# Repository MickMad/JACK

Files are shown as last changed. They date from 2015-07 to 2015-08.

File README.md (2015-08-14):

#JACK
##Just Another Cortex Kit

A Cortex-M0+ development kit with an Atmel SAM D21, a USB device port, a regulator, some passives, a programming header, and breakout headers.

Arduino Zero compatible.

Software is here:

https://github.com/MickMad/ArduinoCore-samd/

```
Copyright © Michele Perla 2015

This documentation describes Open Hardware and is licensed under the CERN OHL v. 1.2.
You may redistribute and modify this documentation under the terms of the CERN OHL v.1.2. 
(http://ohwr.org/cernohl). This documentation is distributed
WITHOUT ANY EXPRESS OR IMPLIED WARRANTY, INCLUDING OF
MERCHANTABILITY, SATISFACTORY QUALITY AND FITNESS FOR A
PARTICULAR PURPOSE. Please see the CERN OHL v.1.2 for applicable
conditions
```

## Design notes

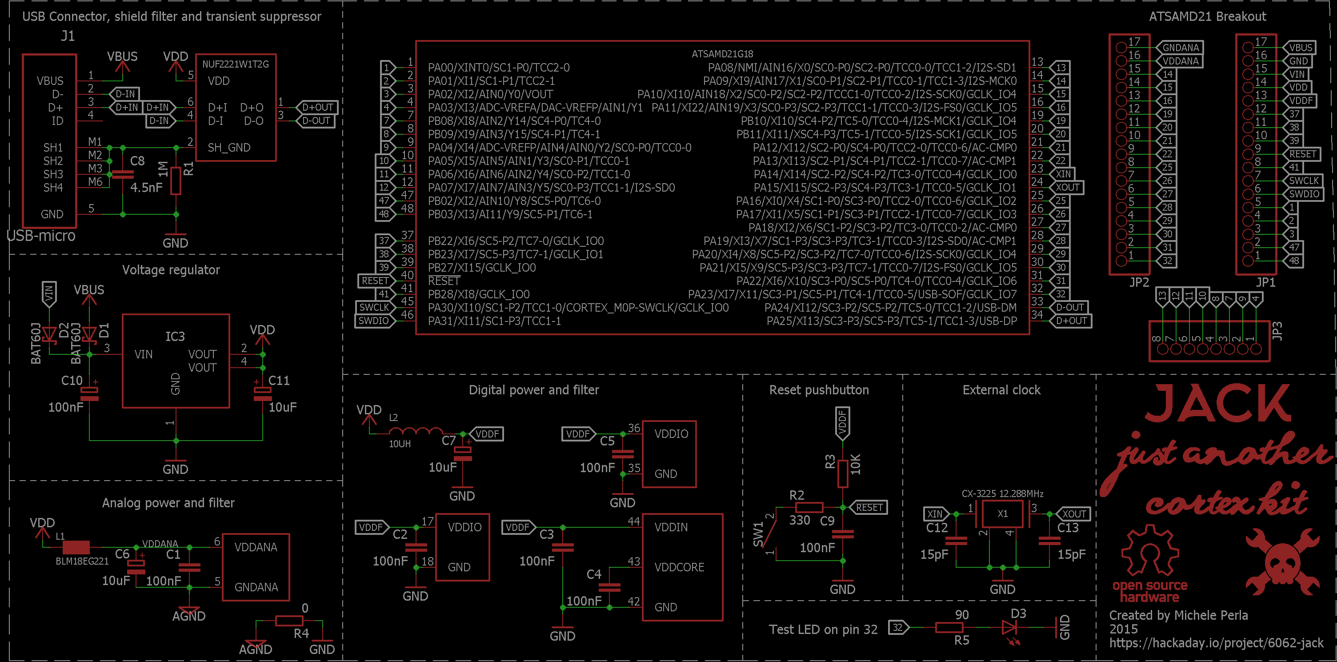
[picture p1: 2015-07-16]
graphics/jack - schematic.png

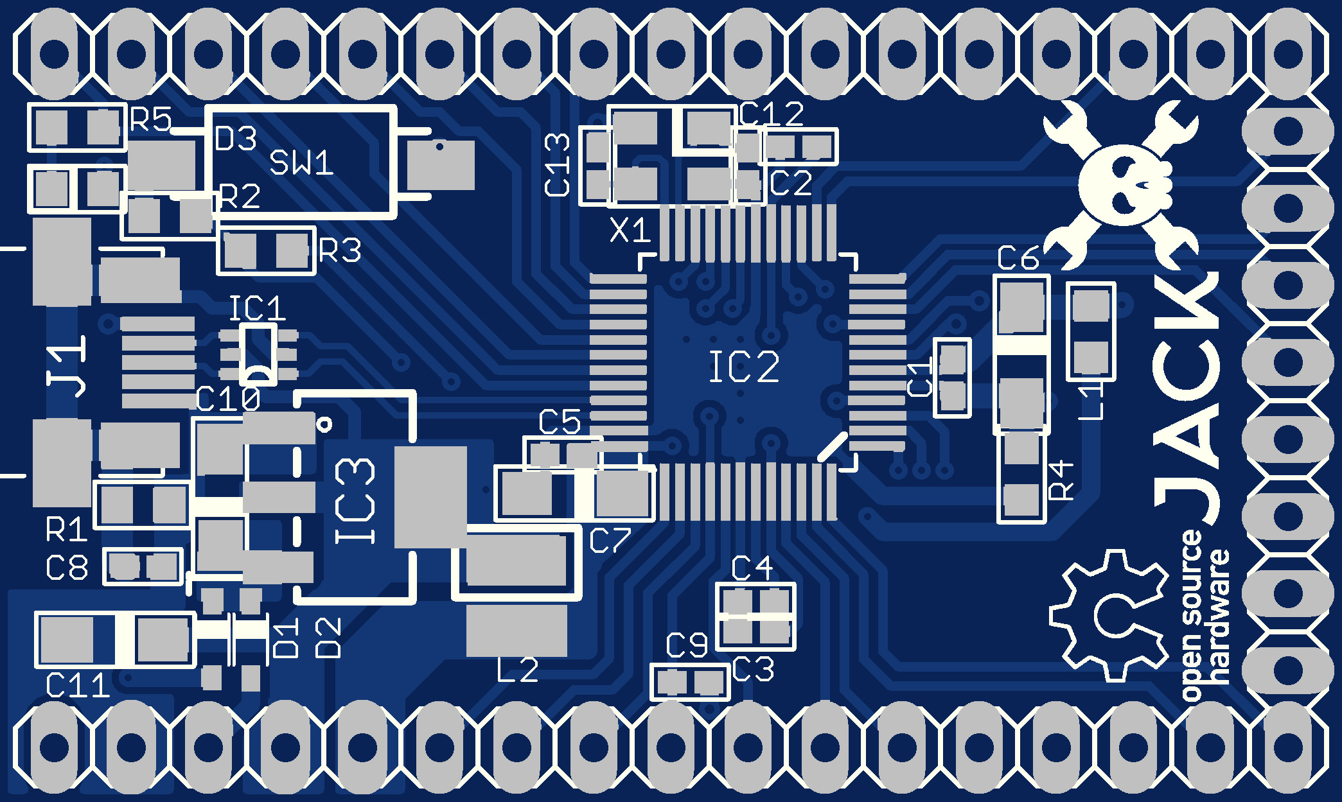
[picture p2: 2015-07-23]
eagleUp/eagleUp_jack_board_top.jpg

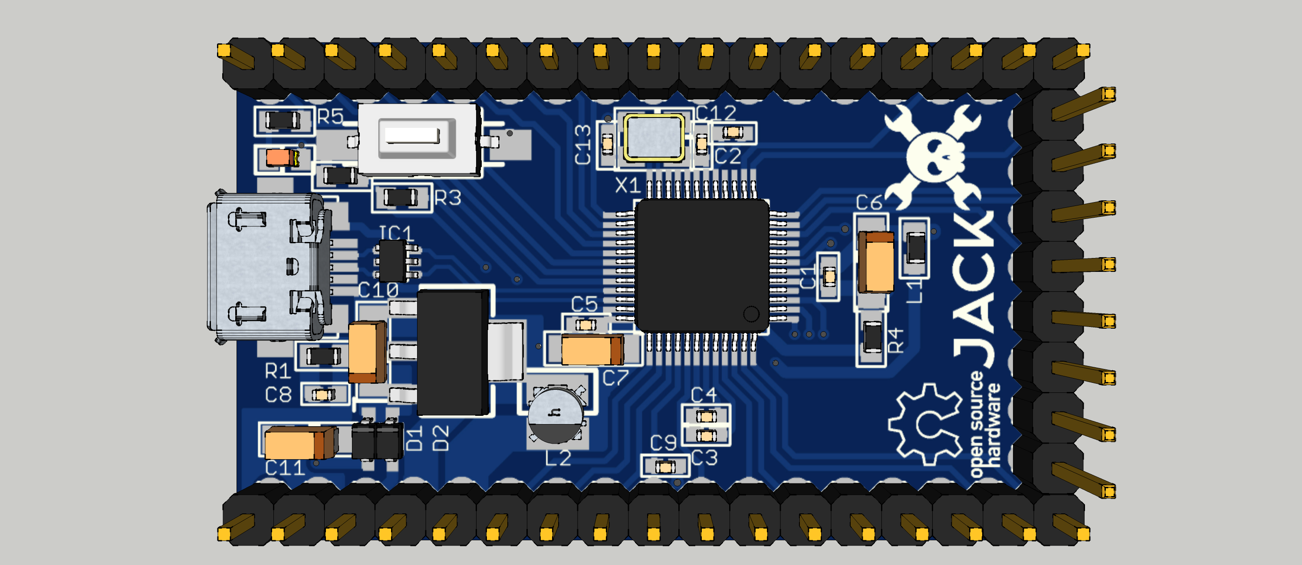
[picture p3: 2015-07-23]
graphics/jack - 3D preview - top.png

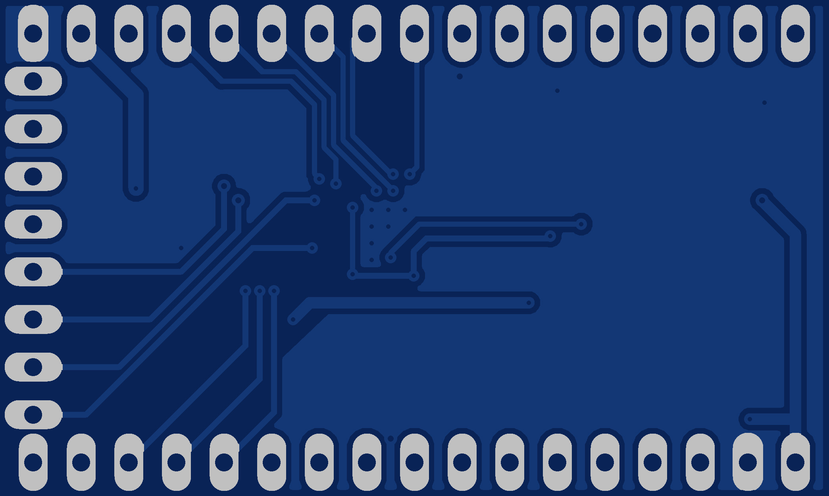
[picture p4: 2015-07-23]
eagleUp/eagleUp_jack_board_bottom.jpg

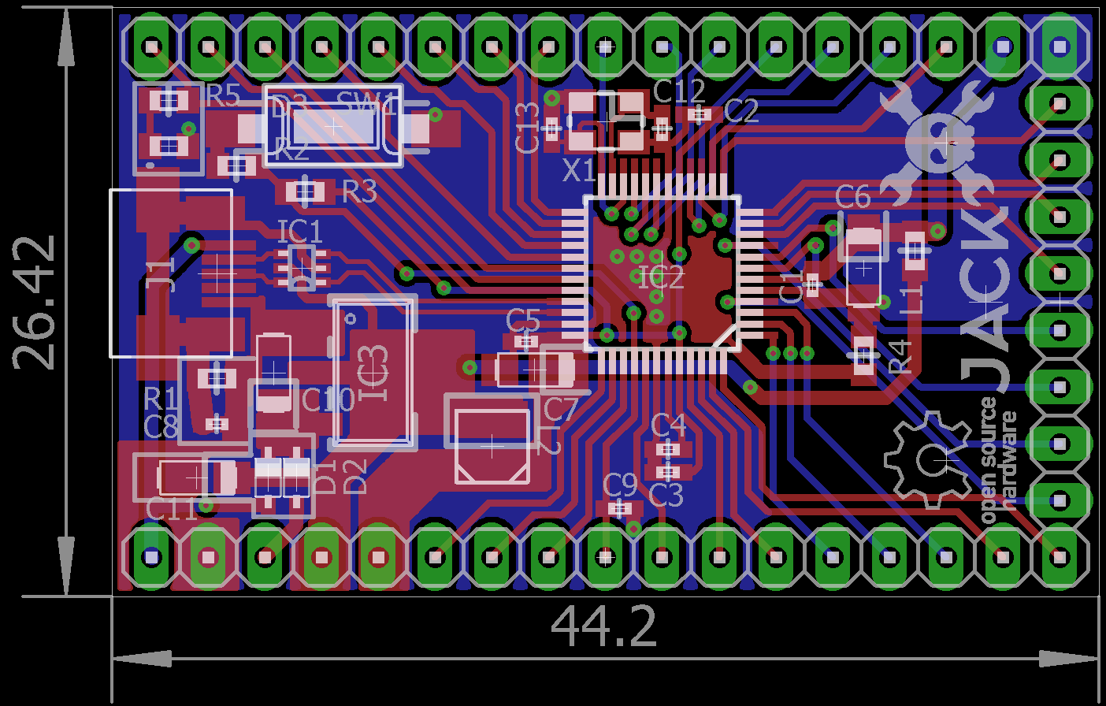
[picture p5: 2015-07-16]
graphics/jack - layout.png

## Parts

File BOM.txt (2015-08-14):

Partlist exported from C:/Users/mperla.CORP/Documents/GitHub/JACK/jack.sch at 16/07/2015 16:05

Part Value             Device          Package            Description                                                            
C1   100nF             C-EU            C0402K                                                                                    
C2   100nF             C-EU            C0402K                                                                                    
C3   100nF             C-EU            C0402K                                                                                    
C4   100nF             C-EU            C0402K                                                                                    
C5   100nF             C-EU            C0402K                                                                                  
C9   100nF             C-EU            C0402K

C8   4.5nF             C-EU            C0402K  
                                                                                    
C6   10uF              CPOL-EU         SMC_P                                                                                     
C7   10uF              CPOL-EU         SMC_P                                                                                                                                                                        
C10  10uF              CPOL-EU         SMC_P                                                                                     
C11  10uF              CPOL-EU         SMC_P   
                                                                                  
C12  15pF              C-EU            C0402K                                                                                    
C13  15pF              C-EU            C0402K 
                                                                                   
D1   BAT60J            BAT60J          SOD323_ST          Schottky barrier diode                                                 
D2   BAT60J            BAT60J          SOD323_ST          Schottky barrier diode  
                                               
D3   LED               LED             LED-0603           Blue LED                                                               
IC1  NUF2221W1T2G      NUF2221W1T2G    SOT-363            ON SEMICONDUCTOR NUF2221W1T2G  IC, FILTER, USB, ESD PROTECTION, SOT363 
IC2  ATSAMD21G18       ATSAMD21G18     TQFP48                                                                                    
IC3  NCV1117ST33T3G    NCV1117ST33T3G  SOT-223-3          ON Semiconductor LDO 3.3V 1.0A Automotive                                                                       
J1   USB-micro         47346-0001      MOLEX_47346-0001   CONN RCPT 5POS MICRO USB R/A  SMD                                      

JP1                    PINHD-1X17      1X17               PIN HEADER                                                             
JP2                    PINHD-1X17      1X17               PIN HEADER                                                             
JP3                    PINHD-1X8       1X08               PIN HEADER  
                                                           
L1   BLM18EG221        L               0603               Ferrite bead                                                           
L2   10UH              ELLVFG100MC-VXG IND_ELLVXG         Choke Coils   
                                                         
R1   1M                R-EU            R0603                                                                                     
R2   330               R-EU            R0603                                                                                     
R3   10K               R-EU            R0603                                                                                     
R4   0                 R-EU            R0603                                                                                     
R5   68                R-EU            R0603     
                                                                                
SW1  SPST3.5X6MM       SPST3.5X6MM     SWITCH-SMD-3.5X6MM Tactile Switches 3.5X6 SMT TACT TACT SWITCH - Mouser part # 506-FSMSM                                                                                 
X1   CX-3225 12.288MHz XTALCX-3225     CX-3225

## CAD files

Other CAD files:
graphics/jack.skp

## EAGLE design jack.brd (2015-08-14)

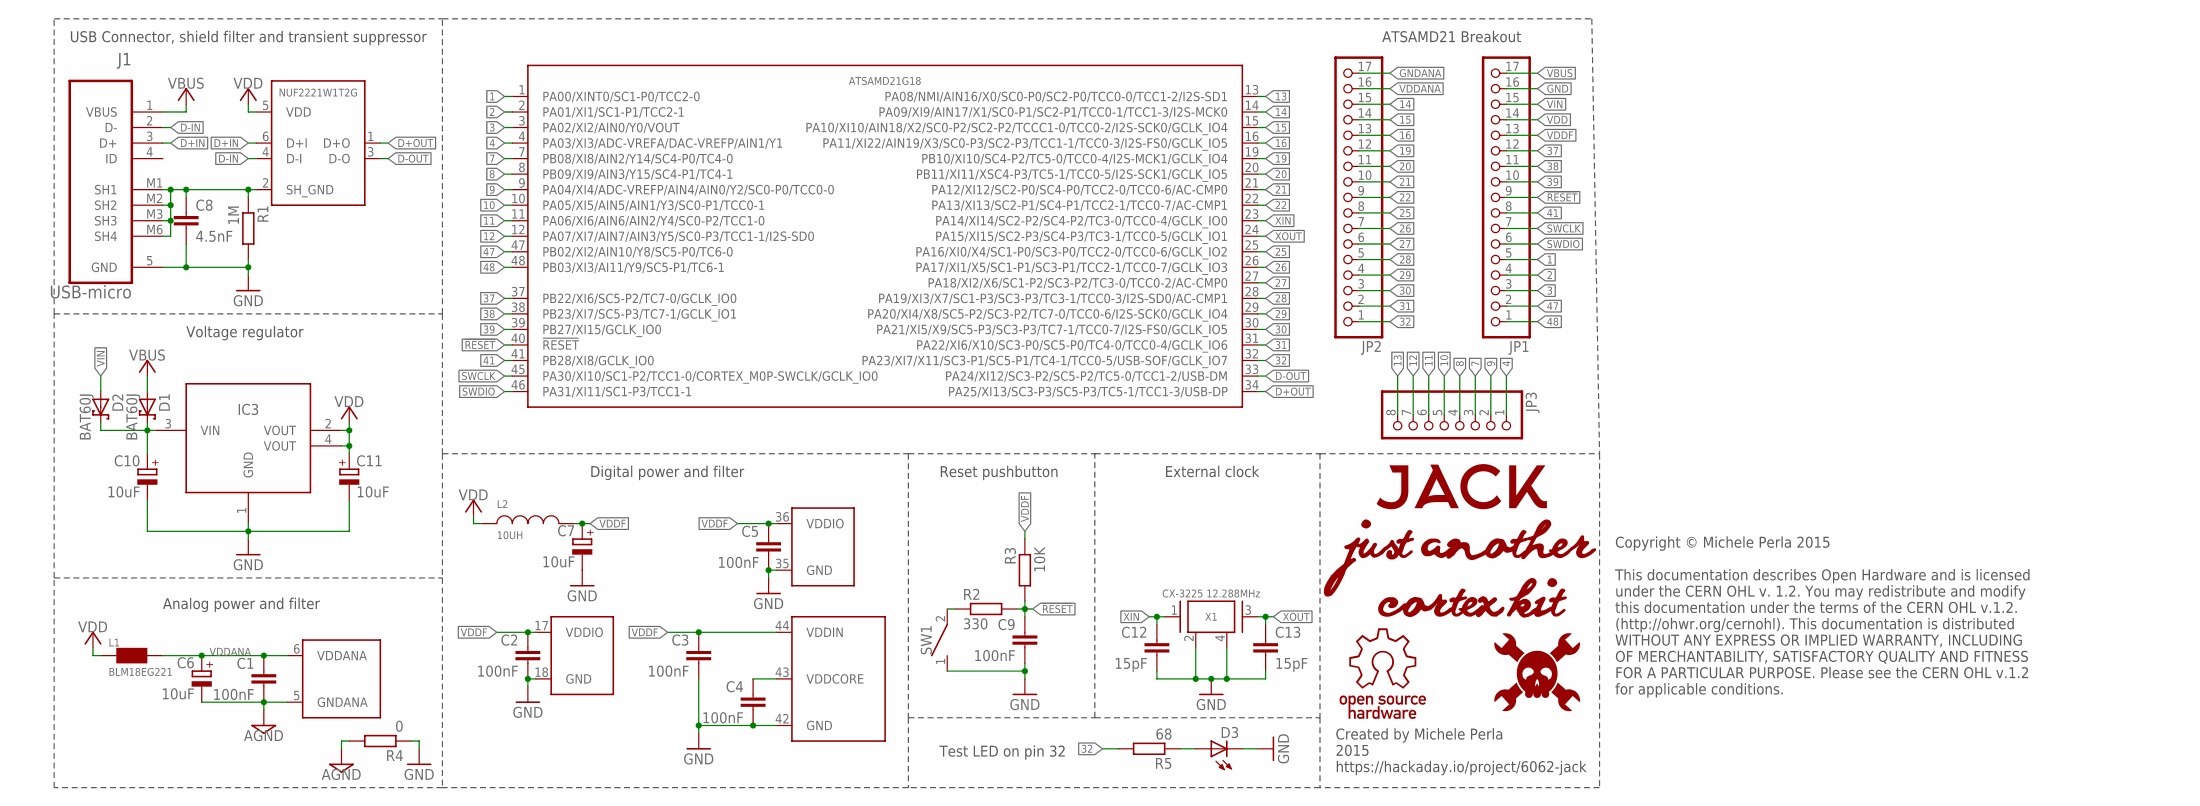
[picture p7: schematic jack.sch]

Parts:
C1, C2, C3, C4, C5, C9: 100nF; C0402
C6, C7, C10, C11: 10uF; CT3216
C8: 4.5nF; C0402
C12, C13: 15pF; C0402
D1, D2: BAT60J; SOD323_ST
D3: LED; LED-0603
IC1: NUF2221W1T2G; SOT-363
IC2: ATSAMD21G18; TQFP48
IC3: LDO; SOT-223-3
J1: USB-micro; MOLEX_47346-0001
JP1, JP2: PINHD-1X17; 1X17
JP3: PINHD-1X8; 1X08
L1: BLM18EG221; 0603
L2: 10UH; IND_ELLVXG
R1: 1M; R0603
R2: 330; R0603
R3: 10K; R0603
R4: 0; R0603
R5: 68; R0603
SW1: SPST3.5X6MM; SWITCH-SMD-3.5X6MM
U$3: JACK-LOGO
U$5: HAD-LOGO
U$6: OSHW-LOGO
X1: CX-3225 12.288MHz; CX-3225

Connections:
1: IC2.1 (PA00/XINT0/SC1-P0/TCC2-0), JP1.5
2: IC2.2 (PA01/XI1/SC1-P1/TCC2-1), JP1.4
3: IC2.3 (PA02/XI2/AIN0/Y0/VOUT), JP1.3
4: IC2.4 (PA03/XI3/ADC-VREFA/DAC-VREFP/AIN1/Y1), JP3.1
7: IC2.7 (PB08/XI8/AIN2/Y14/SC4-P0/TC4-0), JP3.3
8: IC2.8 (PB09/XI9/AIN3/Y15/SC4-P1/TC4-1), JP3.4
9: IC2.9 (PA04/XI4/ADC-VREFP/AIN4/AIN0/Y2/SC0-P0/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), JP3.2
10: IC2.10 (PA05/XI5/AIN5/AIN1/Y3/SC0-P1/TCC0-1), JP3.5
11: IC2.11 (PA06/XI6/AIN6/AIN2/Y4/SC0-P2/TCC1-0), JP3.6
12: IC2.12 (PA07/XI7/AIN7/AIN3/Y5/SC0-P3/TCC1-1/I2S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), JP3.7
13: IC2.13 (PA08/NMI/AIN16/X0/SC0-P0/SC2-P0/TCC0-0/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), JP3.8
14: IC2.14 (PA09/XI9/AIN17/X1/SC0-P1/SC2-P1/TCC0-1/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), JP2.15
15: IC2.15 (PA10/XI10/AIN18/X2/SC0-P2/SC2-P2/TCCC1-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), JP2.14
16: IC2.16 (PA11/XI22/AIN19/X3/SC0-P3/SC2-P3/TCC1-1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), JP2.13
19: IC2.19 (PB10/XI10/SC4-P2/TC5-0/TCC0-4/I2S-MCK1/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), JP2.12
20: IC2.20 (PB11/XI11/XSC4-P3/TC5-1/TCC0-5/I2S-SCK1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), JP2.11
21: IC2.21 (PA12/XI12/SC2-P0/SC4-P0/TCC2-0/TCC0-6/A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), JP2.10
22: IC2.22 (PA13/XI13/SC2-P1/SC4-P1/TCC2-1/TCC0-7/A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), JP2.9
25: IC2.25 (PA16/XI0/X4/SC1-P0/SC3-P0/TCC2-0/TCC0-6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), JP2.8
26: IC2.26 (PA17/XI1/X5/SC1-P1/SC3-P1/TCC2-1/TCC0-7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), JP2.7
27: IC2.27 (PA18/XI2/X6/SC1-P2/SC3-P2/TC3-0/TCC0-2/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), JP2.6
28: IC2.28 (PA19/XI3/X7/SC1-P3/SC3-P3/TC3-1/TCC0-3/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), JP2.5
29: IC2.29 (PA20/XI4/X8/SC5-P2/SC3-P2/TC7-0/TCC0-6/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), JP2.4
30: IC2.30 (PA21/XI5/X9/SC5-P3/SC3-P3/TC7-1/TCC0-7/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), JP2.3
31: IC2.31 (PA22/XI6/X10/SC3-P0/SC5-P0/TC4-0/TCC0-4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), JP2.2
32: IC2.32 (PA23/XI7/X11/SC3-P1/SC5-P1/TC4-1/TCC0-5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), JP2.1, R5.2
37: IC2.37 (PB22/XI6/SC5-P2/TC7-0/GCLK_IO0), JP1.12
38: IC2.38 (PB23/XI7/SC5-P3/TC7-1/GCLK_IO1), JP1.11
39: IC2.39 (PB27/XI15/GCLK_IO0), JP1.10
41: IC2.41 (PB28/XI8/GCLK_IO0), JP1.8
47: IC2.47 (PB02/XI2/AIN10/Y8/SC5-P0/TC6-0), JP1.2
48: IC2.48 (PB03/XI3/AI11/Y9/SC5-P1/TC6-1), JP1.1
!RESET: C9.1, IC2.40 (!RESET), JP1.9, R2.2, R3.2
D+IN: IC1.6 (D+I), J1.3 (D+)
D+OUT: IC1.1 (D+O), IC2.34 (PA25/XI13/SC3-P3/SC5-P3/TC5-1/TCC1-3/US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)
D-IN: IC1.4 (D-I), J1.2 (D-)
D-OUT: IC1.3 (D-O), IC2.33 (PA24/XI12/SC3-P2/SC5-P2/TC5-0/TCC1-2/US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)
GND: C2.2, C3.2, C4.2, C5.2, C7.-, C8.2, C9.2, C10.-, C11.-, C12.2, C13.2, D3.C, IC2.18 (GND), IC2.35 (GND), IC2.42 (GND), IC3.1 (GND), J1.5 (GND), JP1.16, R1.2, R4.1, SW1.1, X1.2 (GND), X1.4 (GND)
GNDANA: C1.2, C6.-, IC2.5 (GNDANA), JP2.17, R4.2
LDOIN: C10.+, D1.C, D2.C, IC3.3 (VIN)
unnamed: D3.A, R5.1
unnamed: R2.1, SW1.2
SH_GND: C8.1, IC1.2 (SH_GND), J1.M1 (SH1), J1.M2 (SH2), J1.M3 (SH3), J1.M6 (SH4), R1.1
SWCLK: IC2.45 (PA30/XI10/SC1-P2/TCC1-0/CORTEX_M0P-SWCL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), JP1.7
SWDIO: IC2.46 (PA31/XI11/SC1-P3/TCC1-1), JP1.6
VBUS: D1.A, J1.1 (VBUS), JP1.17
VDD: C11.+, IC1.5 (VDD), IC3.2 (VOUT), IC3.4 (VOUT), JP1.14, L1.1, L2.2
VDDANA: C1.1, C6.+, IC2.6 (VDDANA), JP2.16, L1.2
VDDCORE: C4.1, IC2.43 (VDDCORE)
VDDF: C2.1, C3.1, C5.1, C7.+, IC2.17 (VDDIO), IC2.36 (VDDIO), IC2.44 (VDDIN), JP1.13, L2.1, R3.1
VIN: D2.A, JP1.15
XIN: C12.1, IC2.23 (PA14/XI14/SC2-P2/SC4-P2/TC3-0/TCC0-4/GC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), X1.1
XOUT: C13.1, IC2.24 (PA15/XI15/SC2-P3/SC4-P3/TC3-1/TCC0-5/GC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), X1.3

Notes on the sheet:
USB Connector, shield filter and transient suppressor
Voltage regulator
Analog power and filter
Digital power and filter
Reset pushbutton
External clock
ATSAMD21 Breakout
Created by Michele Perla 2015 https://hackaday.io/project/6062-jack
Test LED on pin 32
Copyright © Michele Perla 2015 This documentation describes Open Hardware and is licensed under the CERN OHL v. 1.2. You may redistribute and modify this documentation under the terms of the CERN OHL v.1.2. (http://ohwr.org/cernohl). This documentation is distributed WITHOUT ANY EXPRESS OR IMPLIED 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

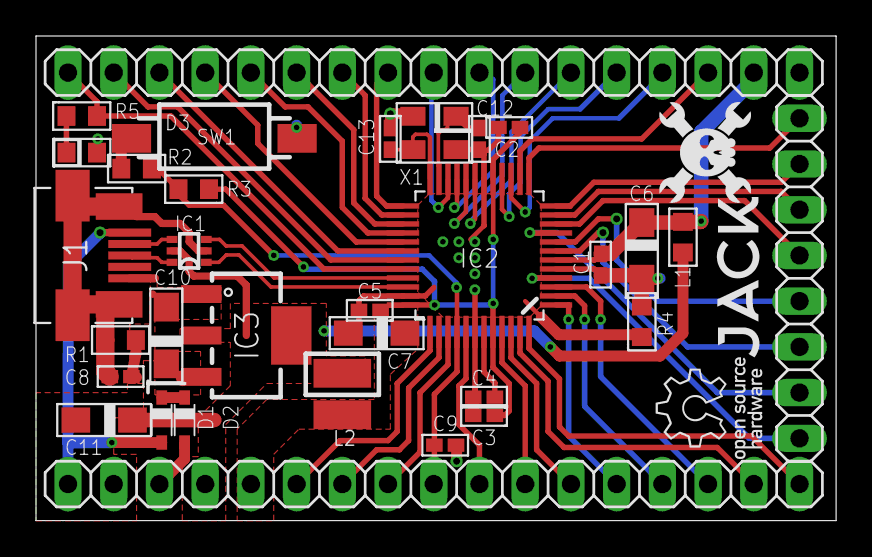
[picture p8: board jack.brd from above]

Board: 2 copper layers, 44.5 x 26.9 mm, 35 parts (0 on the bottom side), 53 nets.

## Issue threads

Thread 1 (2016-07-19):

Final board?

dronecz, 2016-07-19:
Hi @MickMad

are these files for your board final? I´m looking for some small board with SAMD21G18 and I like your design. I would like place an order to PCB fab so please let me know.

Thanks

MickMad, 2016-07-20:
Not at all, the pins are oddly mapped, there's no silkscreen for their label, the board is not as small as it could be, and since I started working on HACK (https://github.com/MickMad/HACK) I stopped improving on this design. I will take it up again when I tackle I2S on this chip. You may take HACK as a starting point, but bear in mind there could be some layout issue there too. :)

dronecz, 2016-07-20:
Thanks for reply. I looked at HACK and to be honest I like more JACK and I donť use Kicad so HACK is not usable for now. Can you tell me what worked and what not on JACK? I mean things like loading sketches, SPI, I2C and things like that. If I make this board and populate it, will be working?

MickMad, 2016-07-20:
The prototypes I have here worked, but there are some issues. USB won't work in sketch mode, which is a big drawback. I'm sure there's something going on with the clock generator that does not like the fact that we're not running the thing with a 32.768 KHz crystal. Plus, the code (for both modified bootloader and modified core) is not there anymore, you may have to rewrite it. I might check on the PC if I have some old version left over.  Also, there's a known issue with the reset-to-bootloader thingy (it's called double-tap-reset but it works once every 10 times), you may want to enable the bootloader pin.

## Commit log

2015-06-01 :boom: Added project, schematic, libraries and README files
    [jack.sch]
2015-06-04 :grin: Added SPST symbol, modded SAMD21 pin names
    Added SPST symbol for the reset switch (still got to find a suitable
    tact switch), modified the SAMD21 pin names to show all their functions
    [jack.sch]
2015-06-09 :+1: Added LDO and graphics
    Added 3.3 V LDO in library and schematic, added graphics for logo
    (temporary?)
    [jack.sch]
2015-06-12 :goat: Added 24 MHZ crystal
    Added 24 MHZ crystal
    [jack.sch]
2015-06-16 :memo: Added headers, protection diodes
    Added protection diodes (reverse voltage/current for external power
    input), dded pinout headers to schematic. Now I only got to decide how
    to arrange pins on the breakout :smile:
    [jack.sch]
2015-06-17 :+1: Finished 1st schematic rev, created jack.brd
    Finished first schematic revision (pin layout), created jack.brd layout
    file, minor modifications to two downloaded component packages (text
    size and position)
    [jack.brd, jack.sch]
2015-06-18 :octocat: Moved a few components on layout
    Started layout process.... I'm going really slow (work is a pain)
    [jack.brd, jack.sch]
2015-06-25 :hatching_chick: Polished schematic, started layout
    I polished the schematic so to let people easily understand what does
    what, dividing it in sections with a description; I did a hi-res picture
    of it so to see it without having to open Eagle CAD; also, I started the
    layout process; you can already see on the PCB where stuff should go in
    the end
    [jack.brd, jack.sch]
2015-06-25 :wavy_dash: Progressing with layout
    Still dealing with layout, in particular dealing with analog/digital
    power, decoupling caps and correct power grounding (one ground to rule
    them all, or local a/d planes near chip and then star ground near LDO?)
    [jack.brd, jack.sch]
2015-06-26 Minor changes
    [jack.brd, jack.sch]
2015-07-01 :satellite: Modified .gitignore, updated schematic, progressing layout
    [jack.brd, jack.sch]
2015-07-01 :paperclip: Ultimating critical parts layout
    Finishing crystal, decoupling caps and USB signals an parts layout;
    trying to figure out where to move the rest...
    [jack.brd, jack.sch]
2015-07-02 Started power signals layout
    [jack.brd, jack.sch]
2015-07-02 :thumbsup: Updated mcu pins/breakout header map
    I'm mapping the pins of the ATSAM21D to the breakout header in a way
    that reduces airwires length on the PCB, thus easing the layout process
    [jack.brd, jack.sch]
2015-07-06 PCB layout almost done, changed breakout configuration accordingly
    [jack.brd, jack.sch]
2015-07-06 :feelsgood: Layout finished!
    Minor details gotta be worked now (polishing pours layout)
    [jack.brd, jack.sch]
2015-07-07 :thumbsup: minor project update (polishing stuff)
    Added new screenshots, little tweaks to schematic and layout (ground
    fills, power signals fills). The design is still missing a logo though
    [jack.brd, jack.sch]
2015-07-08 :feelsgood: Totally done now!
    Added LED on pin 23, added logos (hackaday, oshw, JACK)
    [jack.brd, jack.sch]
2015-07-09 :octocat: Added stopmask on logos
    Now the logos will look all shiny and clear! woohoo
    [jack.brd]
2015-07-10 :suspect: Revision 2! (pre-prototype fix)
    Changed 10uF to polarized tantalum caps, changed packages accordingly,
    had to move some stuff around, also had to add/resize some copper pours,
    finally added polarity marks and place marks on all parts to give a more
    detailed (readable) silk mask.
    [jack.brd]
2015-07-15 :sleepy: Reduced board size!
    I managed to shrink the board in less than 3X5 cm^2. It now features an
    8 pin header on the left side so to let the board fit under 5 cm on both
    sides, to get cheapest PCB manufactury.
    [jack.brd]
2015-07-16 Minor changes (added BOM)
    [jack.brd, jack.sch]
2015-07-16 :grin: Added eagleUp folder, modded jack.lbr
    I'm testing 3D view of the PCB with components on it because it's cool
    and because it'll let me see if the components would overlap in real
    life. I'm also modding the jack.lbr file to show little squares around
    little parts on silkscreen, to triple-check packages sizes, and to match
    packages names with eagleUp model names. I'll eventually add the final
    SketchUp file of it.
2015-07-16 Updated .sch and .brd to match changes in library files
    Ops, I forgot to save and close the project before pushing the last
    commit :grin:
    [jack.brd, jack.sch]
2015-07-23 :feelsgood: Added BOM, Gerbers, 3D model and render
    [jack.brd, jack.sch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]
2015-08-14 Updated BOM, JACK logo package, GERBERS, licence, readme
    [jack.sch]
2015-08-14 Update of gerber files
    [jack.brd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]
